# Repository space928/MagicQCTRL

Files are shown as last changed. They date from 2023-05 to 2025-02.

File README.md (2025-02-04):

# MagicQCTRL
A custom controller for the MagicQ lighting software built around the Adafruit MacroPad RP2040.


## Building
The project is split into two parts, the software which runs on the macropad and the client application.

### Macropad Software
The software running on the MacroPad is a simple Arduino project which can be built using the PlatformIO extension for VSCode.

### Client Application
The client application is written in .NET 7 and can be built with any modern version of Visual Studio with support for .NET 7.

## Data Flow

```

  ==================       USB HID Messages    [________________ - [] X ]                          [_______________ - [] X ]
  | O  #####  O  O |   ----- Key Press ----->  [                        ]  ---- OSC Message ---->  [ MagicQ                ]
  | O  [] [] []  O |   ---- Button Press --->  [                        ]                          [                       ]
  | O  [] [] []  O |   ---- Encoder Move --->  [                        ]  ---- Memory Read ---->  [                       ]
  | O  [] [] []  O |                           [                        ]  <--- Memory Write ----  [                       ]
  |    [] [] []    |   <-- Update Profile ---  [                        ]                          [                       ]
  |                |                           [                        ]                          [                       ]
  ==================                           [________________________]                          [                       ]
  MagicQ CTRL Hardware                         Client app                                          MagicQ

```

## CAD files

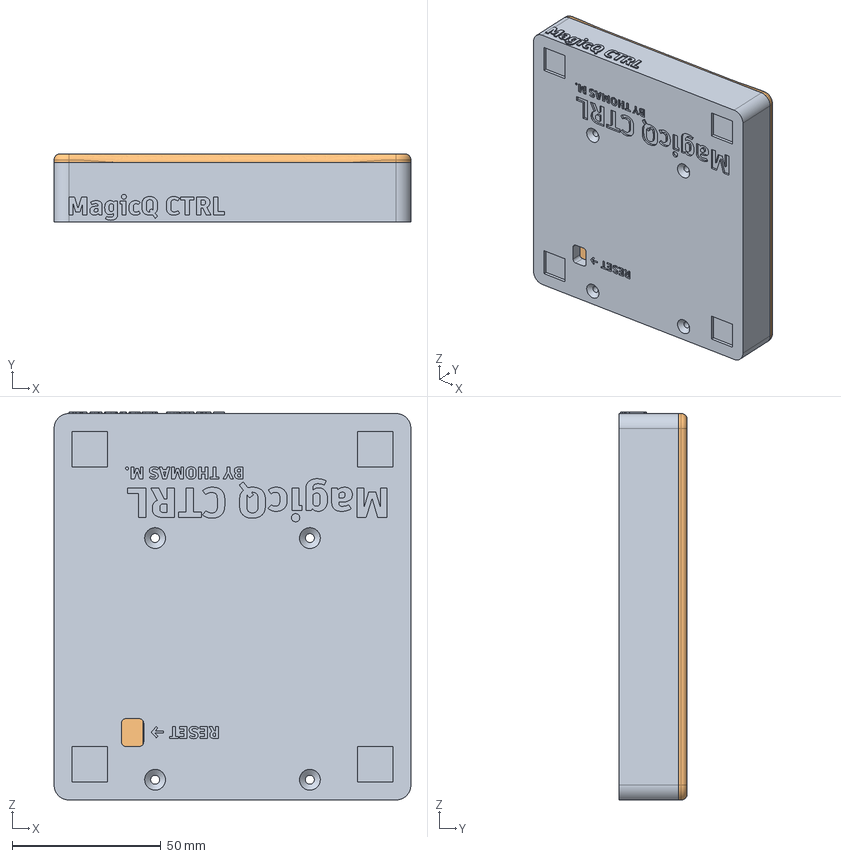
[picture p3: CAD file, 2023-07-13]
CAD/MagicQCtrlPad v22_box.step
120.0 x 23.0 x 130.5 mm

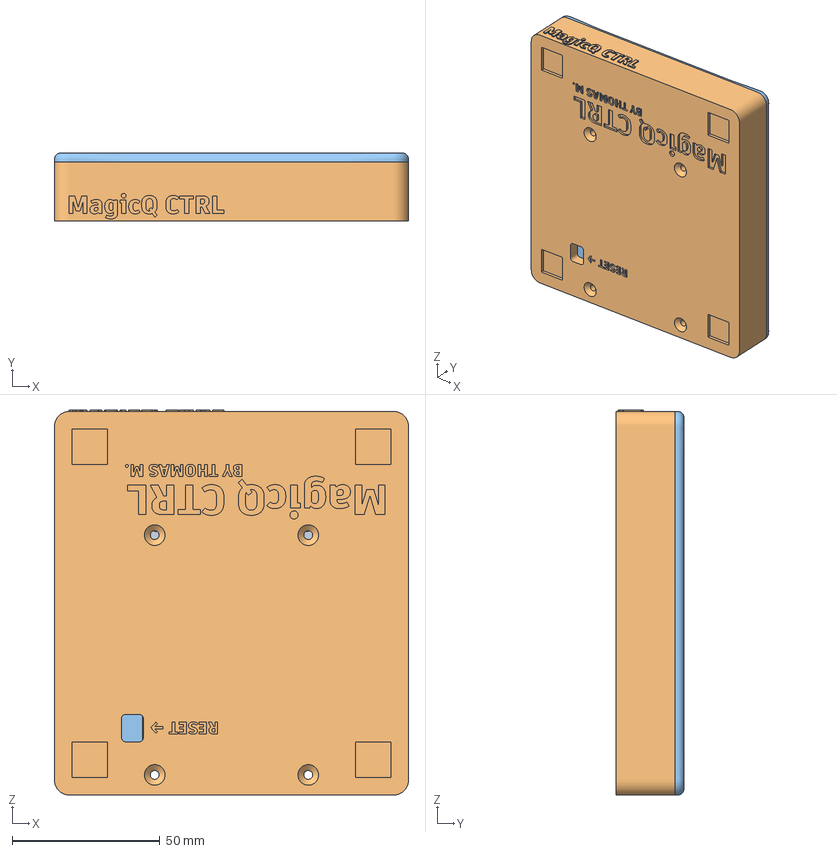
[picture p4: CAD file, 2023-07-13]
CAD/MagicQCtrlPad v22.3mf
120.0 x 23.0 x 130.5 mm
Board
Lid

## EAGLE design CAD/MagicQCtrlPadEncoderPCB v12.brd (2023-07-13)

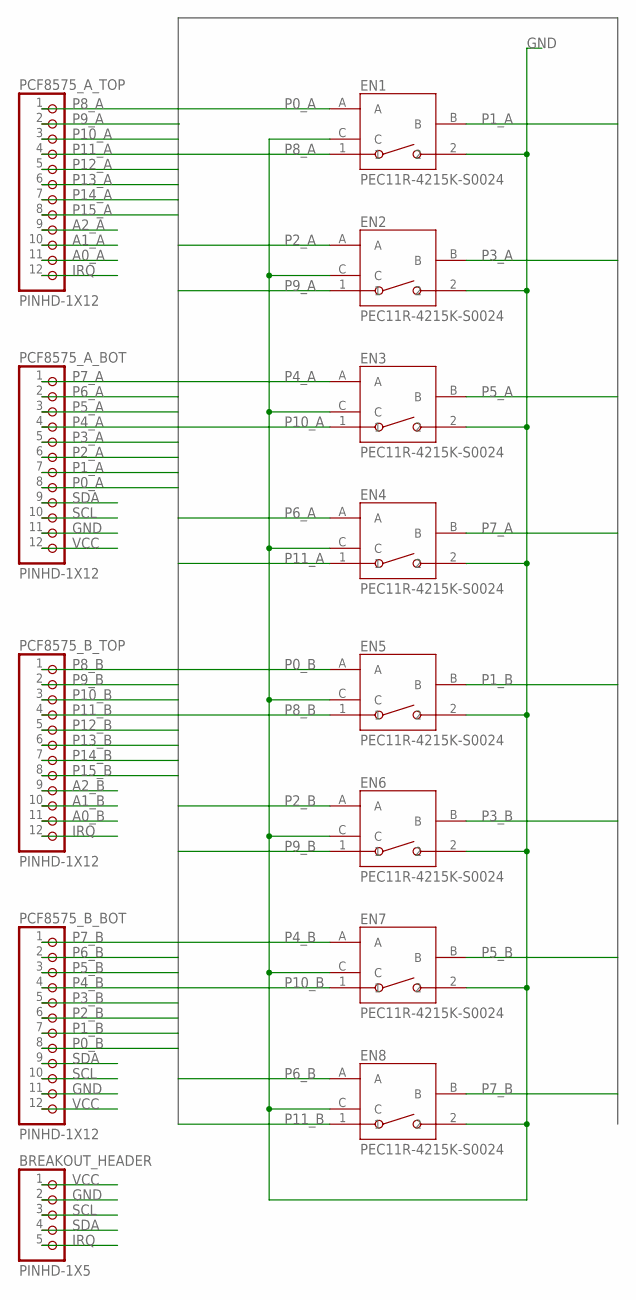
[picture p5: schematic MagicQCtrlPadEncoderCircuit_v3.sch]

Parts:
BREAKOUT_HEADER: PINHD-1X5; 1X05
EN1, EN2, EN3, EN4, EN5, EN6, EN7, EN8: PEC11R-4215K-S0024
PCF8575_A_BOT, PCF8575_A_TOP, PCF8575_B_BOT, PCF8575_B_TOP: PINHD-1X12; 1X12

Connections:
A0_A: PCF8575_A_TOP.11
A0_B: PCF8575_B_TOP.11
A1_A: PCF8575_A_TOP.10
A1_B: PCF8575_B_TOP.10
A2_A: PCF8575_A_TOP.9
A2_B: PCF8575_B_TOP.9
GND: BREAKOUT_HEADER.2, EN1.2, EN1.C, EN2.2, EN2.C, EN3.2, EN3.C, EN4.2, EN4.C, EN5.2, EN5.C, EN6.2, EN6.C, EN7.2, EN7.C, EN8.2, EN8.C, PCF8575_A_BOT.11, PCF8575_B_BOT.11
IRQ: BREAKOUT_HEADER.5, PCF8575_A_TOP.12, PCF8575_B_TOP.12
P0_A: EN1.A, PCF8575_A_BOT.8
P0_B: EN5.A, PCF8575_B_BOT.8
P1_A: EN1.B, PCF8575_A_BOT.7
P1_B: EN5.B, PCF8575_B_BOT.7
P2_A: EN2.A, PCF8575_A_BOT.6
P2_B: EN6.A, PCF8575_B_BOT.6
P3_A: EN2.B, PCF8575_A_BOT.5
P3_B: EN6.B, PCF8575_B_BOT.5
P4_A: EN3.A, PCF8575_A_BOT.4
P4_B: EN7.A, PCF8575_B_BOT.4
P5_A: EN3.B, PCF8575_A_BOT.3
P5_B: EN7.B, PCF8575_B_BOT.3
P6_A: EN4.A, PCF8575_A_BOT.2
P6_B: EN8.A, PCF8575_B_BOT.2
P7_A: EN4.B, PCF8575_A_BOT.1
P7_B: EN8.B, PCF8575_B_BOT.1
P8_A: EN1.1, PCF8575_A_TOP.1
P8_B: EN5.1, PCF8575_B_TOP.1
P9_A: EN2.1, PCF8575_A_TOP.2
P9_B: EN6.1, PCF8575_B_TOP.2
P10_A: EN3.1, PCF8575_A_TOP.3
P10_B: EN7.1, PCF8575_B_TOP.3
P11_A: EN4.1, PCF8575_A_TOP.4
P11_B: EN8.1, PCF8575_B_TOP.4
P12_A: PCF8575_A_TOP.5
P12_B: PCF8575_B_TOP.5
P13_A: PCF8575_A_TOP.6
P13_B: PCF8575_B_TOP.6
P14_A: PCF8575_A_TOP.7
P14_B: PCF8575_B_TOP.7
P15_A: PCF8575_A_TOP.8
P15_B: PCF8575_B_TOP.8
SCL: BREAKOUT_HEADER.3, PCF8575_A_BOT.10, PCF8575_B_BOT.10
SDA: BREAKOUT_HEADER.4, PCF8575_A_BOT.9, PCF8575_B_BOT.9
VCC: BREAKOUT_HEADER.1, PCF8575_A_BOT.12, PCF8575_B_BOT.12

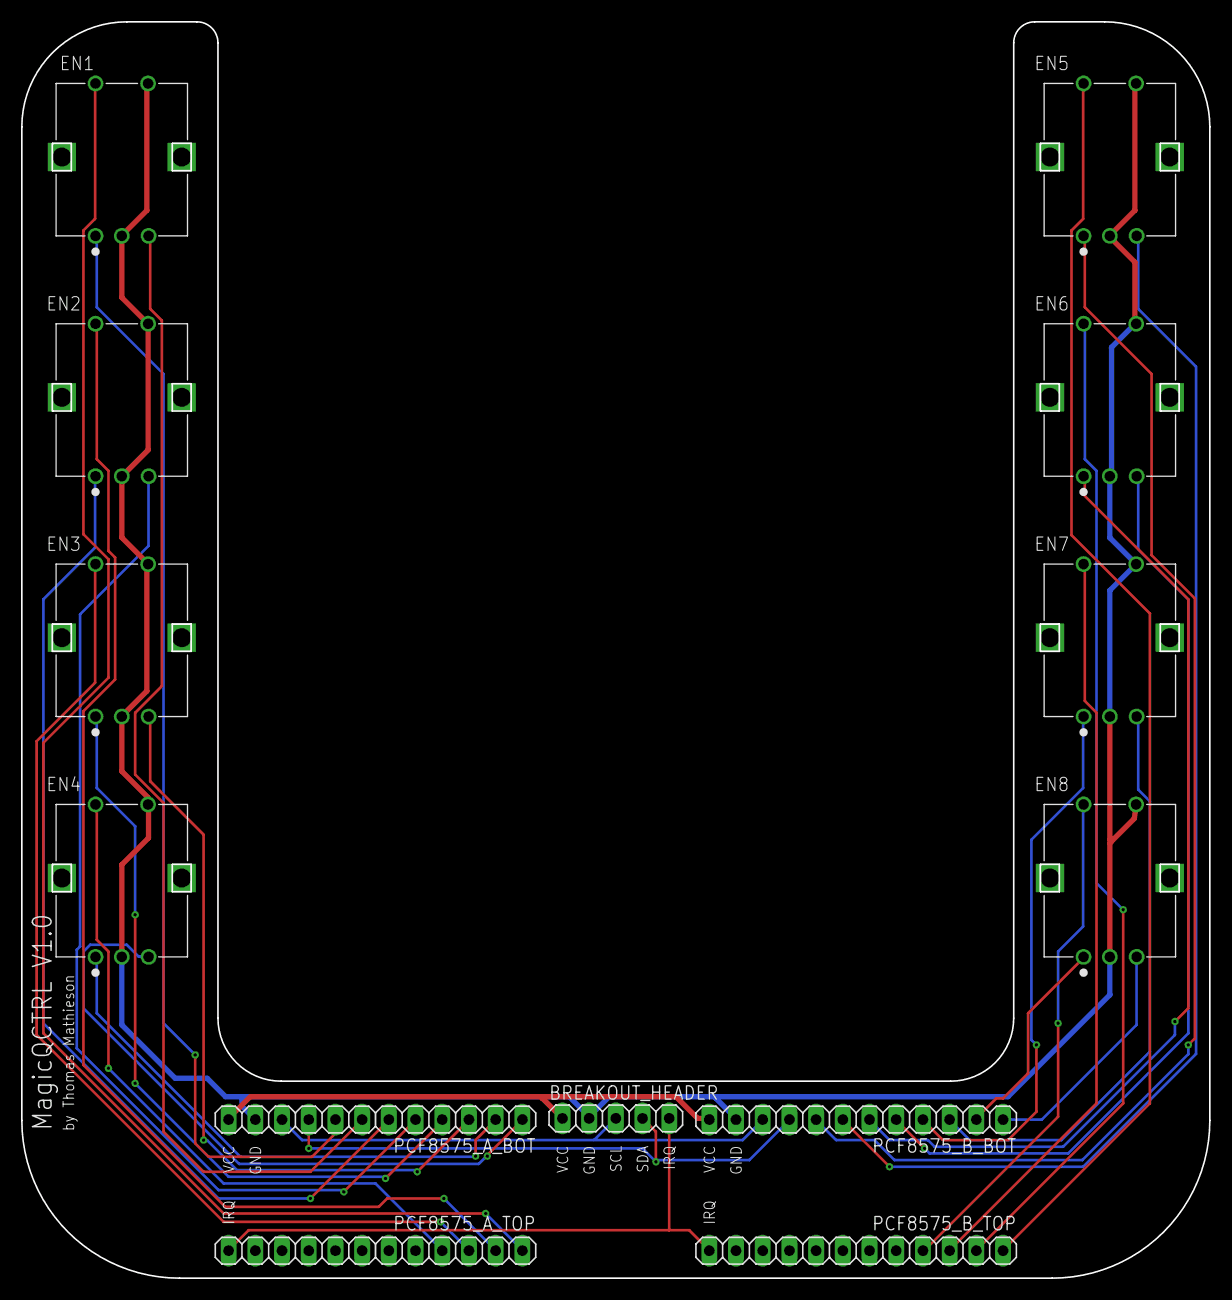
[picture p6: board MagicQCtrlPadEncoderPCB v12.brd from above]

Board: 2 copper layers, 113.0 x 119.5 mm, 13 parts (0 on the bottom side), 29 nets.

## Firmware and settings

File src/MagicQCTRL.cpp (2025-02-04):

#include <Arduino.h>
// #include <pins_arduino.h>
#include <Adafruit_SH110X.h>
#include <Adafruit_NeoPixel.h>
#include <RotaryEncoder.h>
#include <Wire.h>
#include "Config.h"
#include "debug.h"
#include "Globals.h"
#include "Display.h"
#include "HID.h"
#include "EncoderKeysIO.h"

// ===================================
// GLOBALS
// Create the neopixel strip with the built in definitions NUM_NEOPIXEL and PIN_NEOPIXEL
Adafruit_NeoPixel pixels = Adafruit_NeoPixel(NUM_NEOPIXEL, PIN_NEOPIXEL, NEO_GRB + NEO_KHZ800);

// ===================================
// LOCALS
uint8_t j = 0;

// ===================================
// METHODS
void setup()
{
    setupDebug();
    // while (!Serial) { delay(10); }     // wait till serial port is opened
    delay(100); // RP2040 delay is not a bad idea

    dbg_log_info("MagicQ CTRL V" VERSION_STRING " Init");

    // start pixels!
    pixels.begin();
    pixels.setBrightness(DEFAULT_BRIGHTNESS);
    pixels.show(); // Initialize all pixels to 'off'

    // Setup everything required for the OLED
    setupDisplay();

    // Setup everything required for the encoders and keys
    setupIO();

    // Setup the hid device
    initHID();

    display.setCursor(0, 16);
    display.println("Initialised!");
    display.display();

    // Startup animation <3
    startupAnim();

    dbg_log_info("Initialisation completed!");
}

void loop()
{
    tickIO();
    pixels.show();
    updateDisplay();

    j++;
}

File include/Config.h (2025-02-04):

/*
 * Configuration file storing compile time defaults and config variables
 */

#ifndef CONFIG_H
#define CONFIG_H


// ===================================
// CONSTS
#define DISPLAY_TIMEOUT 1000 // Display timeout in ms
#define N_PAGES 3 // How many pages of keys are allowed
#define N_KEYS 12
#define N_ENCODERS 8
#define ENABLE_DEBUG_PAGE 0 // Set to 1 to enable; 0 to disable
#define DEFAULT_BRIGHTNESS 128 // Default neopixel brightness 0-255
#define KEY_NAME_LENGTH 6
#define DISPLAY_WIDTH 128
#define DISPLAY_HEIGHT 64
#define VERSION_STRING "1.6"
#define PCF_L_ADDR 0x20
#define PCF_R_ADDR 0x21
#define ENCODER_MSG_RATE 40
#define ENCODER_ACCELERATION 1.7

///////////////////////////////////////
//// DEBUGGING CONSTS
// Serial Logging
#define DEBUG_SERIAL_LOGGING

// Uncomment whichever level of logging you want
// #define DEBUG_VERBOSE
#define DEBUG_INFO
// #define DEBUG_WARNING
// #define DEBUG_FATAL

#endif //CONFIG_H

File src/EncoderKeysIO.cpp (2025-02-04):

#include <RotaryEncoder.h>
#include <Wire.h>
#include "Config.h"
#include "debug.h"
#include "Display.h"
#include "Globals.h"
#include "HID.h"

// ===================================
// GLOBALS
// Create the rotary encoder
RotaryEncoder encoder(PIN_ROTB, PIN_ROTA, RotaryEncoder::LatchMode::FOUR3);

// our encoder position state
int encoder_pos = 0;
bool encoder_pressed = false;
bool switch_states[N_KEYS] = {false};
uint32_t key_colours_low[N_KEYS * N_PAGES] = {0x4A3520};
uint32_t key_colours_high[N_KEYS * N_PAGES] = {0xAAAAAA};
int8_t encoder_states[N_ENCODERS] = {0};
int8_t encoder_dirs[N_ENCODERS] = {0};
uint8_t encoder_switches[N_ENCODERS] = {0};
uint32_t last_encoder_msg_time = 0;
bool encoders_active = false; // Is one of the encoders being turned?

// Rotary encoder state machine from: http://www.mathertel.de/Arduino/RotaryEncoderLibrary.aspx
// The array holds the values -1 for the entries where a position was
// decremented, a 1 for the entries where the position was incremented
// and 0 in all the other (no change or not valid) cases.
const int8_t KNOB_DIR[] = {
    0, -1, 1, 0,
    1, 0, 0, -1,
    -1, 0, 0, 1,
    0, 1, -1, 0};

// ===================================
// METHODS

void checkPosition()
{
    encoder.tick(); // just call tick() to check the state.
}

void checkEncoders()
{
    // Read the vale of the IO expanders
    // dbg_log("INT=%d\n", digitalRead(PIN_SPEAKER));
    if (digitalRead(PIN_SPEAKER) != LOW)
        return;

    uint8_t pcfData[4];
    Wire.requestFrom(PCF_L_ADDR, 2);
    if (Wire.available())
    {
        Wire.readBytes(pcfData, 2);
    }
    Wire.requestFrom(PCF_R_ADDR, 2);
    if (Wire.available())
    {
        Wire.readBytes(pcfData + 2, 2);
    }

    uint32_t encoderData = pcfData[0] | (pcfData[1] << 8) | (pcfData[2] << 16) | (pcfData[3] << 24);

    // dbg_log("Encoder data: " BYTE_TO_BINARY_PATTERN " " BYTE_TO_BINARY_PATTERN " " BYTE_TO_BINARY_PATTERN " " BYTE_TO_BINARY_PATTERN "\n", BYTE_TO_BINARY(pcfData[3]), BYTE_TO_BINARY(pcfData[2]), BYTE_TO_BINARY(pcfData[1]), BYTE_TO_BINARY(pcfData[0]));

    // Each encoder uses 3 pins on the PCF:
    //  0 - E1_RotA
    //  1 - E1_RotB
    //  2 - E1_Switch
    //  3 - E2_RotA
    //  4 - E2_RotB
    //  5 - E2_Switch
    //  ...

    // This algorithm is derived from:
    // http://www.mathertel.de/Arduino/RotaryEncoderLibrary.aspx
    for (int i = 0; i < N_ENCODERS; i++)
    {
        int a = (i % 4) * 2 + (i >= 4 ? 16 : 0);
        int rotA = (encoderData >> a) & 1;
        int rotB = (encoderData >> (a + 1)) & 1;
        // Set the 1 bit of the encoder_switches item to the value of the switch pin
        uint8_t switchVal = (~(encoderData >> (i + (i >= 4 ? 12 : 0) + 8)) & 1);
        encoder_switches[i] ^= (-switchVal ^ encoder_switches[i]) & 1;
        int8_t currState = rotA | (rotB << 1);

        int8_t lastState = encoder_states[i];
        if (lastState != currState)
        {
            encoder_dirs[i] += KNOB_DIR[currState | (lastState << 2)];
            encoder_states[i] = currState;
            // dbg_log("Encoder msg! a=%d b=%d s=%d d=%d a=%d i=%d\n", rotA, rotB, currState, encoder_dirs[i], a, i);
        }
        else
        {
            // dbg_log("Encoder! a=%d b=%d s=%d d=%d a=%d i=%d\n", rotA, rotB, currState, encoder_dirs[i], a, i);
        }
    }
}

// Input a value 0 to 255 to get a color value.
// The colours are a transition r - g - b - back to r.
uint32_t hue2RGB(byte wheelPos)
{
    if (wheelPos < 85)
    {
        return pixels.Color(255 - wheelPos * 3, 0, wheelPos * 3);
    }
    else if (wheelPos < 170)
    {
        wheelPos -= 85;
        return pixels.Color(0, wheelPos * 3, 255 - wheelPos * 3);
    }
    else
    {
        wheelPos -= 170;
        return pixels.Color(wheelPos * 3, 255 - wheelPos * 3, 0);
    }
}

uint8_t scaledMul(uint8_t a, uint8_t b)
{
    return (uint8_t)((a * (uint16_t)b) >> 8);
}

// Input a value 0 to 255 to get a color value.
// The colours are a transition r - g - b - back to r.
uint32_t hue2RGB(uint8_t wheelPos, uint8_t lightness)
{
    if (wheelPos < 85)
    {
        return pixels.Color(scaledMul(255 - wheelPos * 3, lightness), 0, scaledMul(wheelPos * 3, lightness));
    }
    else if (wheelPos < 170)
    {
        wheelPos -= 85;
        return pixels.Color(0, scaledMul(wheelPos * 3, lightness), scaledMul(255 - wheelPos * 3, lightness));
    }
    else
    {
        wheelPos -= 170;
        return pixels.Color(scaledMul(wheelPos * 3, lightness), scaledMul(255 - wheelPos * 3, lightness), 0);
    }
}

void setupIO()
{
    // set rotary encoder inputs and interrupts
    pinMode(PIN_ROTA, INPUT_PULLUP);
    pinMode(PIN_ROTB, INPUT_PULLUP);
    attachInterrupt(digitalPinToInterrupt(PIN_ROTA), checkPosition, PinStatus::CHANGE);
    attachInterrupt(digitalPinToInterrupt(PIN_ROTB), checkPosition, PinStatus::CHANGE);

    // We will use I2C for scanning the Stemma QT port
    Wire.begin();

    // set all mechanical keys to inputs
    for (uint8_t i = 0; i <= 12; i++)
    {
        pinMode(i, INPUT_PULLUP);
    }

    // Disable speaker
    pinMode(PIN_SPEAKER_ENABLE, OUTPUT);
    digitalWrite(PIN_SPEAKER_ENABLE, LOW);
    // Use the speaker pin as an interrupt
    pinMode(PIN_SPEAKER, INPUT_PULLUP);

    // Setup IO expanders
    // Wire.setSCL(PIN_WIRE0_SCL);
    // Wire.setSDA(PIN_WIRE0_SDA);
    Wire.begin();

    // Test the connection with the IO expanders
    Wire.beginTransmission(PCF_L_ADDR);
    uint8_t i2cError = Wire.endTransmission();
    Wire.beginTransmission(PCF_R_ADDR);
    i2cError |= Wire.endTransmission();
    if (i2cError != 0)
    {
        dbg_log_warning("Failed to connect to rotary encoders! Check I2C address and wiring.");
        display.setCursor(0, 8);
        display.println("Failed to connect to rotary encoders!");
        display.display();
        delay(1000);
    }
    else
    {
        // Only enable the encoder interrupt if the IO expanders were detected
        attachInterrupt(digitalPinToInterrupt(PIN_SPEAKER), checkEncoders, PinStatus::FALLING);
    }
}

void startupAnim()
{
    for (int f = 0; f < 50; f++)
    {
        for (int i = 0; i < pixels.numPixels(); i++)
        {
            uint8_t x = i % 3;
            uint8_t y = i / 3;
            uint16_t h = ((uint16_t)(x + y) + (f - 10)) * 8;
            uint8_t b = (uint8_t)min(max(180 - abs(140 - h), 0), 255) / 2;
            pixels.setPixelColor(i, hue2RGB((uint8_t)h, b));
        }
        pixels.show();
        delay(33);
    }
}

void setKeyCol(uint8_t keyId, uint32_t colLow, uint32_t colHigh)
{
    key_colours_low[keyId] = colLow;
    key_colours_high[keyId] = colHigh;
}
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

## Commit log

2023-02-15 Refactoring and new c# project: - Added gitignore - Moved arduino modules to src/modules - Added c# project
2023-05-09 General progress on all fronts: - Added python utility for debugging USB HID messages - Added proposed key layout - Added debugging/logging library to the Arduino project - Added icon - Updated C# as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
    [KeyLayout.xlsx]
2023-05-10 Many improvements and new functionality: - Implemented button editor - Added OSC support - Added key rgb backlight control - Added key names to the OLED - Implemented USB configuration messages - Fix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
    [KeyLayout.xlsx]
2023-05-12 Started implemented MagicQ interoperability: - Project now requires 32-bit compilation for remote method calls to work, currently required for special functions - Added UI for special functions - Add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
2023-05-13 Interoperability with MagicQ: - Added grouping to the items in the SpecialFunctions dropdown - Added support for setting a custom MagicQ keycode (mostly for debugging) - Added loads of new MagicQ key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
2023-05-17 Progress on encoders + Some Tidying: - Added a safety check for invalid specialFunction values from json files - Added EncoderType enum - Rewrote the MagicQDriver class to make it more robust - Added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
2023-07-13 - Added updated CAD files - Added optional PCB CAD files - Added encoder support to C# app (Encoder emulation for MagicQ) - Added dark theme to colour picker - Improved UI - FIxed a few bugs - Added 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
    [MagicQCtrlPad v22.3mf, MagicQCtrlPad v22_box.step, MagicQCtrlPadEncoderCircuit_v3.sch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]
2023-08-29 Implemented support for Execute items: - Added UI for triggering execute items - Implemented data model for execute items - Implemented hooks for execute items - Implemented special OpenLayout, Reset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
    [EncoderKeysIO.cpp]
2024-02-15 Version 1.5: - Added splash screen - Fixed crash with Layout buttons - Fixed execute items - Updated copyright Arduino project: - Reduced encoder message rate and increased acceleration - Added setti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
    [Config.h, Display.cpp, EncoderKeysIO.cpp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]
2024-11-26 OSC NIC selection and various bugfixes: - Enabled project-wide nulable - Refactored/reformated source code for consistency - Various changes to ensure explicit nullability compliance - Fixed connecti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
2025-02-07 Added support for more MagicQ keys: - Added the remaining keys to the MagicQCTRLSpecialFunction enum - Added string formatter to pretty print the key names in the combobox
2026-02-27 Removed old dependencies added support for 64-bit MagicQ: - Removed Fody - Removed ReactiveUI - Replaced [Reative] properties with source generation - Added basic support for MagicQ 1.9.7.3 (this cur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
